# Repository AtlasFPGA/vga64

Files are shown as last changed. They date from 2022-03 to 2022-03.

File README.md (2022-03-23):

# vga64
Adaptador directo de hdmi a vga para la atlasfpga. Diseño usando Kicad 6.0

La profundidad actual que conseguimos de 64 colores usando 2 bits por color, por eso la llamamos vga64 aunque también podría llamarse vga222.

El adaptador puede ser usado solo o con una adaptador vga<->scart si el core lo permite sin problemas.

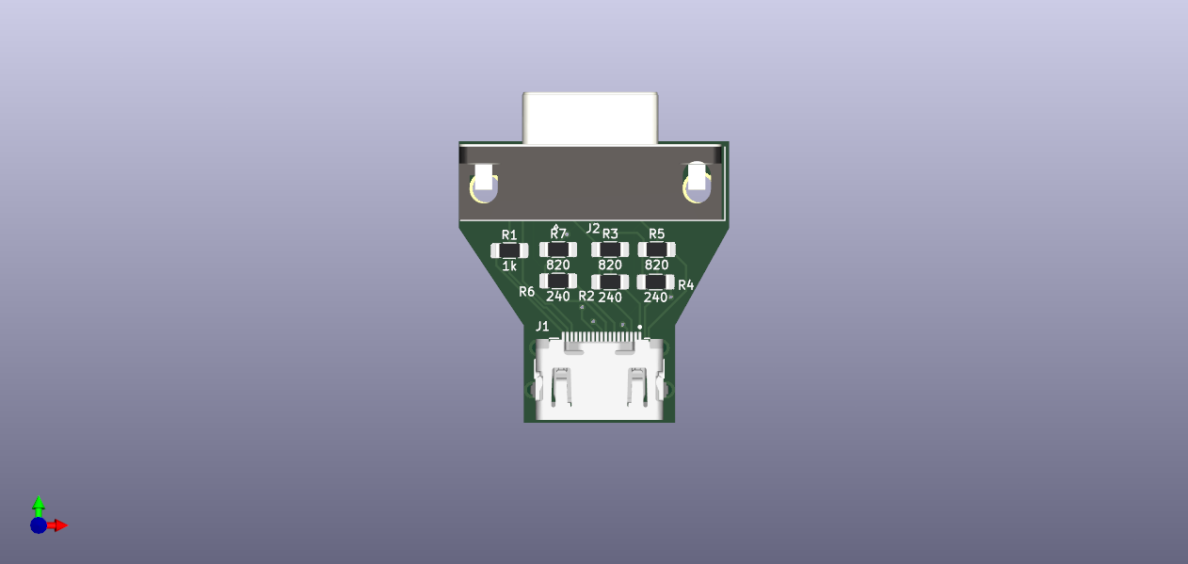
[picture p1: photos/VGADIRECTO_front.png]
FotoFrontal_vga64


# Esquemas
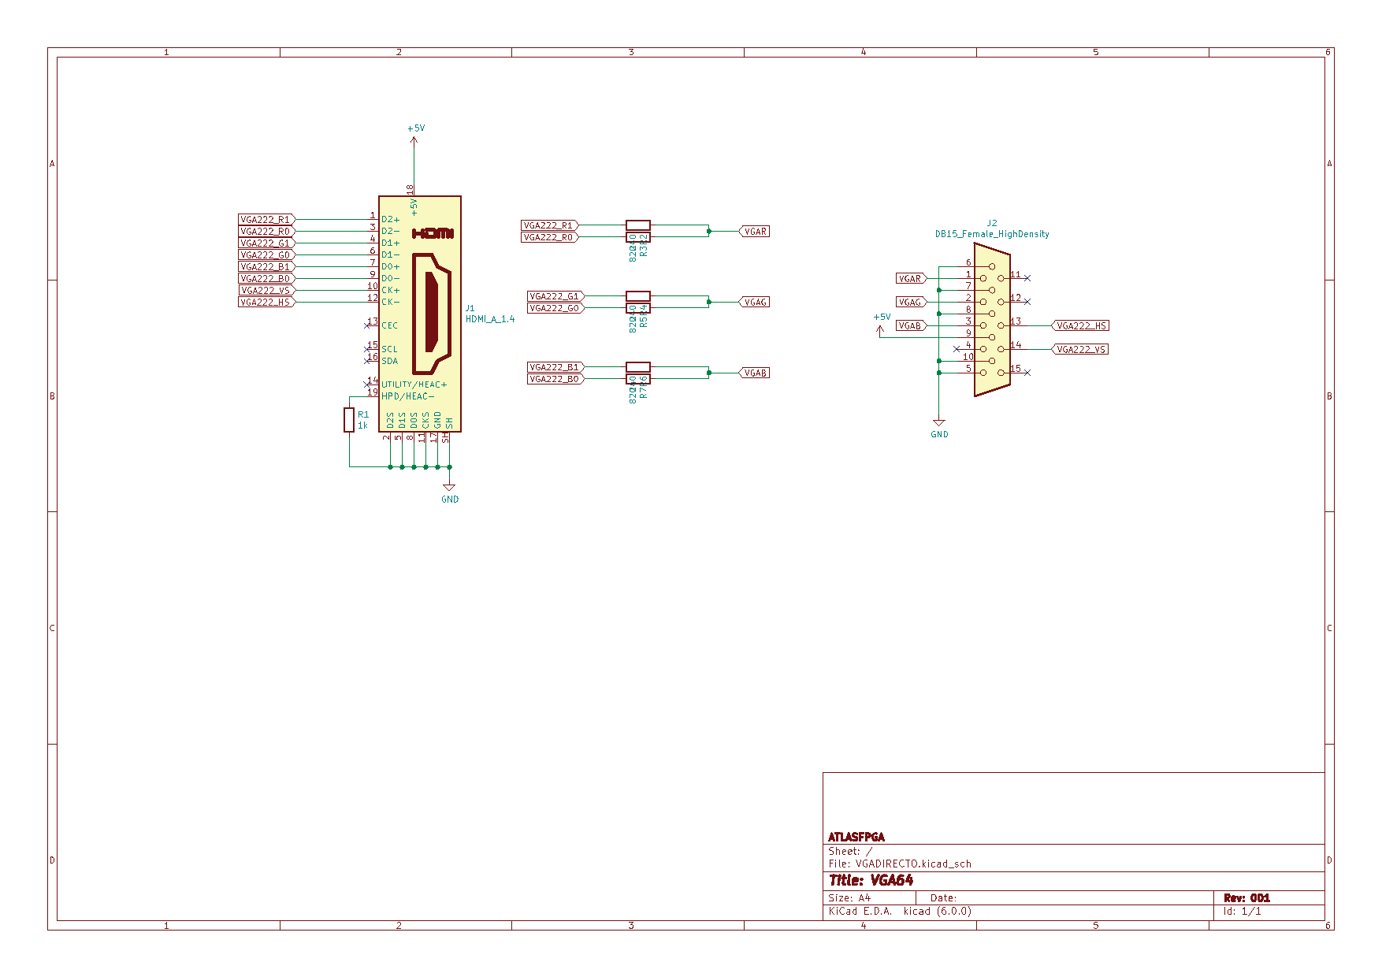
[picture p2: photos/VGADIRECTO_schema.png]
Esquema vga64
[https://github.com/AtlasFPGA/vga64/blob/main/VGADIRECTO.pdf]

# Material
* 1 x PCB vga
* 1 x conector HDMI 
* 1 x conector VGA
* 1 x resistencia 1206 -  1k ohm
* 3 x resistencia 1206 - 820 ohm 
* 3 x resistencia 1206 - 240 ohm

# URL compras
* 1 x PCB lo hicimos en la página https://jlcpcb.com/ usando los gerbers: https://github.com/AtlasFPGA/vga64/raw/main/gerbers_vga64_atlas_1206.zip
* 1 x HDMI modelo 10029449-111RLF -> https://es.farnell.com/amphenol-icc-fci/10029449-111rlf/conector-hdmi-19-pos-hembra-smt/dp/2751197
* 1 x Conector VGA -> https://es.rs-online.com/web/p/conectores-d-sub/6740971
* 1 x resistencia 1206 -  1k ohm -> https://es.farnell.com/multicomp-pro/mp003719/res-1k-1-0-25w-1206-pel-c-gruesa/dp/3392916
* 3 x resistencia 1206 - 820 ohm -> https://es.farnell.com/multicomp-pro/mp003717/res-820r-1-0-25w-1206-pel-c-gruesa/dp/3392914
* 3 x resistencia 1206 - 240 ohm -> https://es.farnell.com/multicomp-pro/mp003703/res-240r-1-0-25w-1206-pel-c-gruesa/dp/3392898

# Equivalencias de pineado para cambiar en Quartus
```
## HDMI Direct ATLAS_V002_CYC1000                                         ### VGA222 adaptador de 64Colores
set_location_assignment PIN_L16 -to TMDS[0] # CLK-                        ### HS
set_location_assignment PIN_L15 -to TMDS[1] # CLK+ # clock channel        ### VS
set_location_assignment PIN_P1 -to TMDS[2]  # 0-                          ### BLUE[0]
set_location_assignment PIN_P2 -to TMDS[3]  # 0+   # blue channel         ### BLUE[1]
set_location_assignment PIN_J1 -to TMDS[4]  # 1-                          ### GREEN[0]
set_location_assignment PIN_J2 -to TMDS[5]  # 1+   # green channel        ### GREEN[1]
set_location_assignment PIN_N1 -to TMDS[6]  # 2-                          ### RED[0]
set_location_assignment PIN_N2 -to TMDS[7]  # 2+   # red channel          ### RED[1]
```

Proyecto original de @subcriticalia y @Nabateo.

Gracias a @Rhoderik por el convertir el proyecto a smd 1206 y a @Somhi (@somhic) por la ayuda / revisión como siempre.

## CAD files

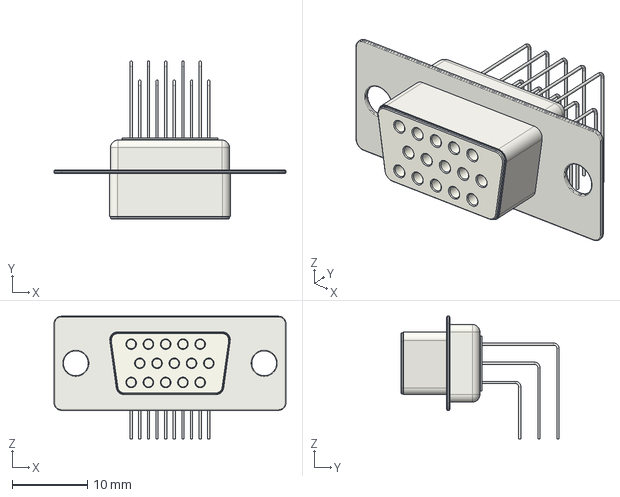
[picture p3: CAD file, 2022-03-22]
3D/DSUB-15-HD_Female_Horizontal_P2.29x2.54mm_EdgePinOffset9.40mm.step
30.8 x 21.0 x 16.3 mm

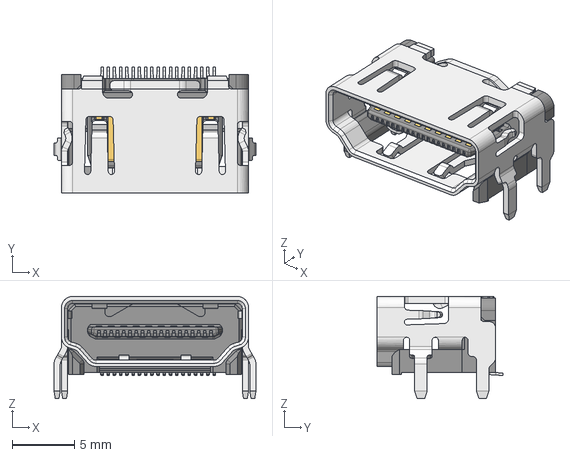
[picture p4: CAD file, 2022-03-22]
hdmi/eec.models/Amphenol_ICC_-_10029449-111RLF.step
16.2 x 10.1 x 8.20 mm

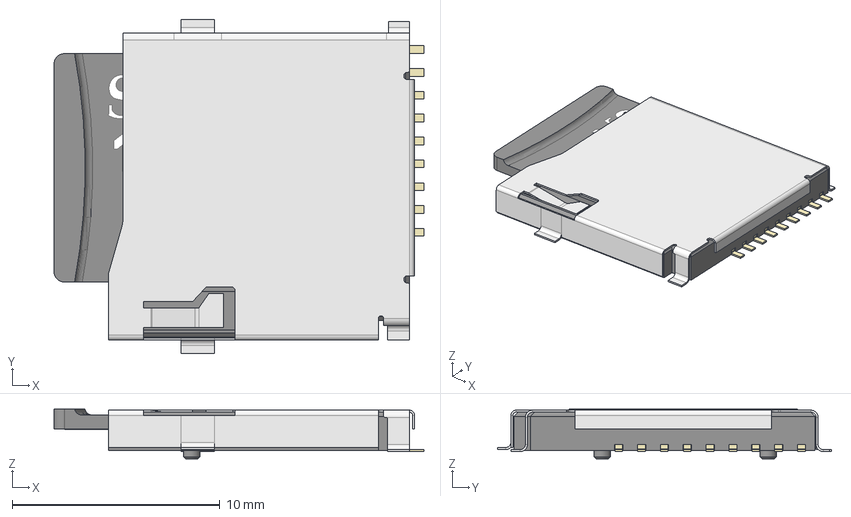
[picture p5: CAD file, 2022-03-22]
3D/TF-01A.step
17.8 x 16.1 x 2.40 mm

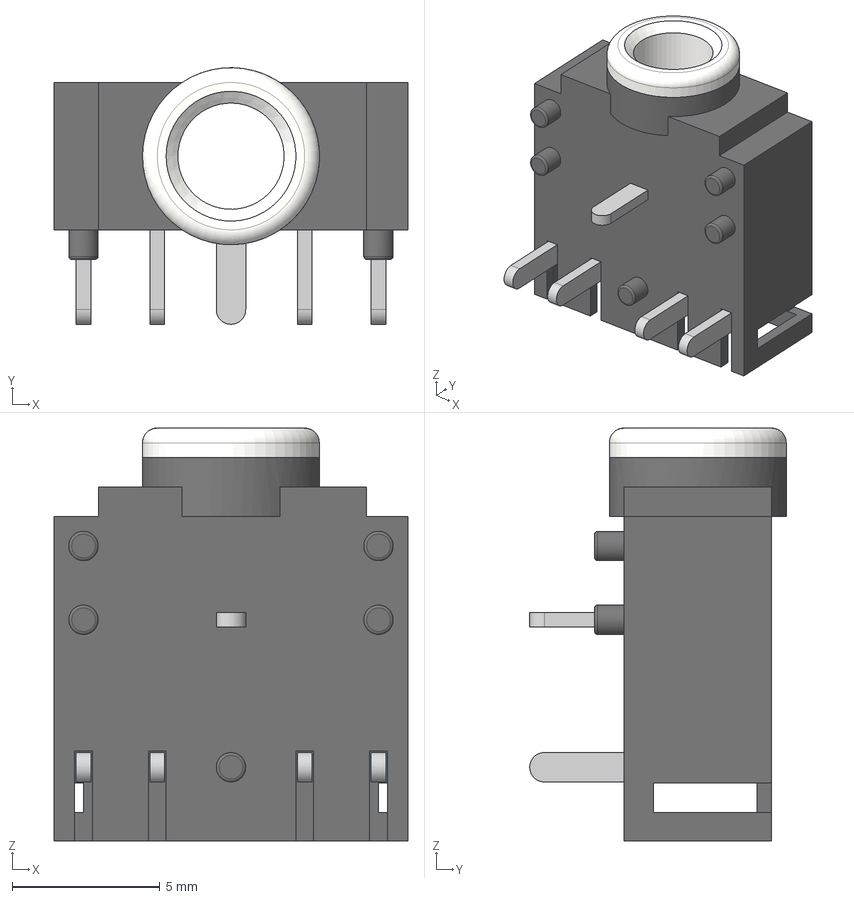
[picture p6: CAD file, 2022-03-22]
3D/pj-307.step
12.0 x 8.70 x 14.0 mm

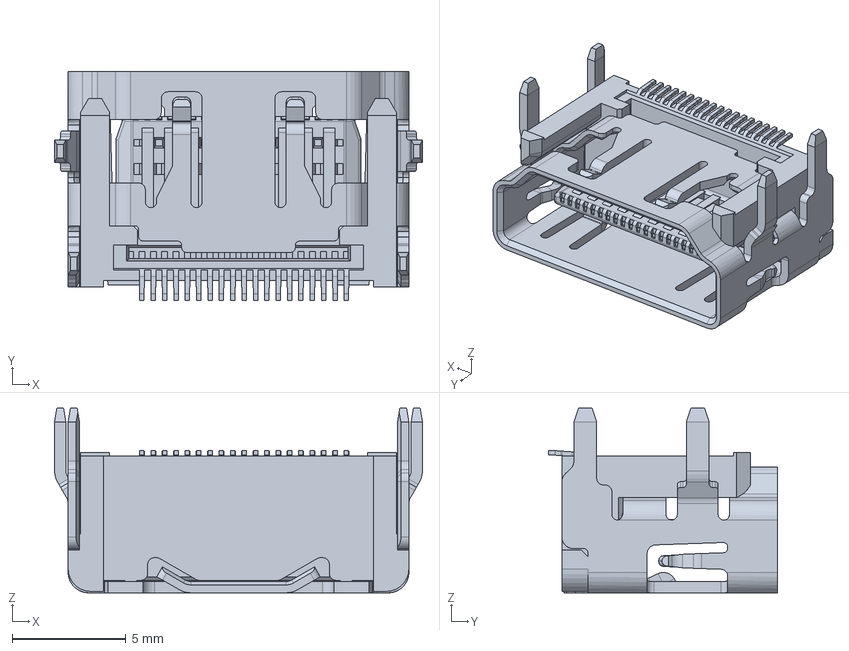
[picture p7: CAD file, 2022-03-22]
3D/10029449-111RLF.stp
16.2 x 10.1 x 8.13 mm

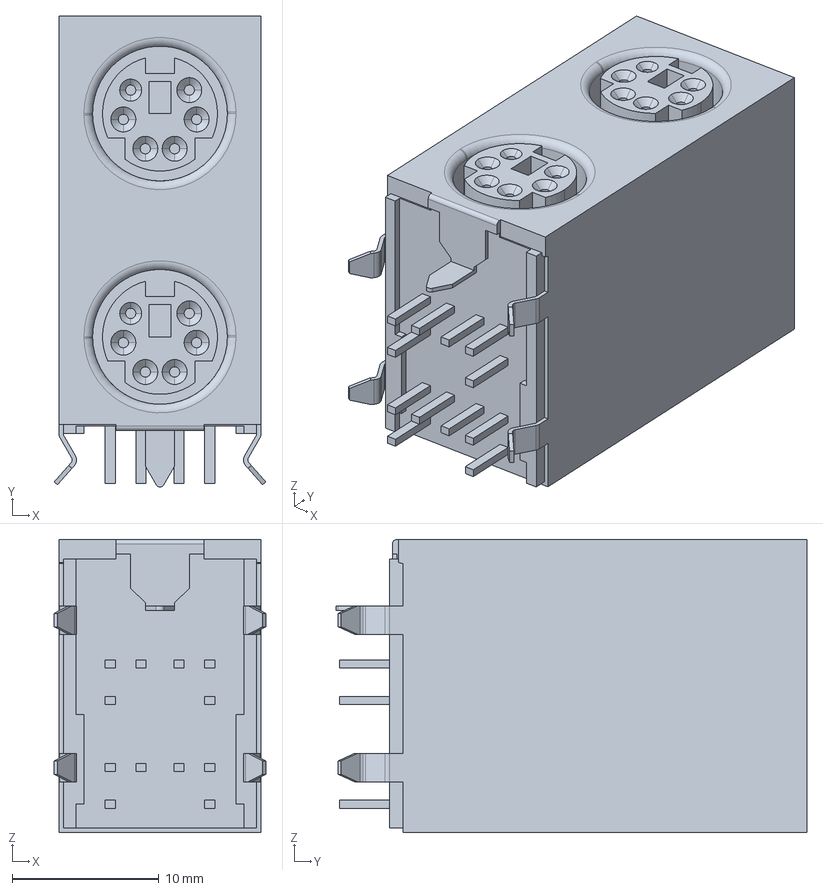
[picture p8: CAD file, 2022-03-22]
3D/1734021-4.stp
14.4 x 32.1 x 20.0 mm

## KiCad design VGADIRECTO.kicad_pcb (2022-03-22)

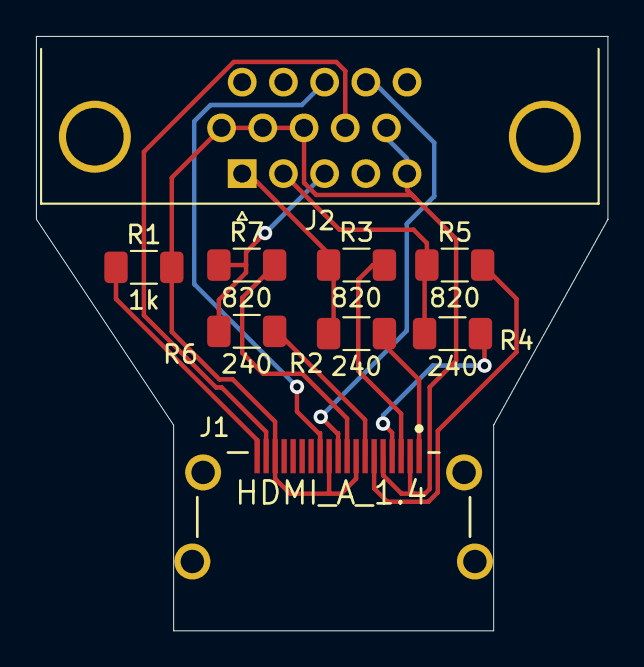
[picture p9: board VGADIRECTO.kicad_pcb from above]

Board: 2 copper layers, 31.8 x 33.0 mm, 9 parts (0 on the bottom side), 14 nets.

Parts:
J1: HDMI_A_1.4; Amphenol_ICC-10029449-111RLF-MFG
J2: DB15_Female_HighDensity; DSUB-15-HD_Female_Horizontal_P2.29x2.54mm_EdgePinOffset3.03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
R1: 1k; R_1206_3216Metric_Pad1.30x1.75mm_HandSolder
R2, R4, R6: 240; R_1206_3216Metric_Pad1.30x1.75mm_HandSolder
R3, R5, R7: 820; R_1206_3216Metric_Pad1.30x1.75mm_HandSolder

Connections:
+5V: J1.18 (+5V), J2.9
GND: J1.2 (D2S), J1.5 (D1S), J1.8 (D0S), J1.11 (CKS), J1.17 (GND), J2.5, J2.6, J2.7, J2.8, J2.10, R1.2
unnamed: J1.19 (HPD/HEAC-), R1.1
VGA222_B0: J1.9 (D0-), R7.2
VGA222_B1: J1.7 (D0+), R6.2
VGA222_G0: J1.6 (D1-), R5.2
VGA222_G1: J1.4 (D1+), R4.2
VGA222_HS: J1.12 (CK-), J2.13
VGA222_R0: J1.3 (D2-), R3.2
VGA222_R1: J1.1 (D2+), R2.2
VGA222_VS: J1.10 (CK+), J2.14
VGAB: J2.3, R6.1, R7.1
VGAG: J2.2, R4.1, R5.1
VGAR: J2.1, R2.1, R3.1

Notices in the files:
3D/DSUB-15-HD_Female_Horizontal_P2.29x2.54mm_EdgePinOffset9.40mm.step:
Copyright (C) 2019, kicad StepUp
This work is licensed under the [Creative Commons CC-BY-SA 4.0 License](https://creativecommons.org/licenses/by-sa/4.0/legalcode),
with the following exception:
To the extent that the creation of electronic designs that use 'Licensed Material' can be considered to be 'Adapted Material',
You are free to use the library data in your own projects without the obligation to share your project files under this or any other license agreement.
